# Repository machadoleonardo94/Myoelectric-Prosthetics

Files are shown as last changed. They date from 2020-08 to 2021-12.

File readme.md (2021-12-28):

# Intro

### This is the prototype for actuating a stepper motor using EMG signals, with the final purpose of studying prosthetic devices. 

### Current model was developed for string based actuation like the e-NABLE hand found at https://enablingthefuture.org/ and still is a work in progress.

### The project started in 2018, and after my graduation it took a big hiatus. Updates are due, and I'm getting back to work with this concept in early 2022.

### Feel free to ask questions and colab in this development. 

### Proof of concept can be seen at https://www.youtube.com/watch?v=dRGHVrhc-jM

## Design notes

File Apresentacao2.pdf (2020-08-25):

# Próteses impressas

Leonardo Machado de Aguiar
Formação | Departamento de Engenharia Elétrica e Eletrônica | CTC

# Problema

### - Custo da prótese estética de membro superior: de

R$3000 a R$10000;

### - Desafio de adaptar o equipamento prostético às

necessidades do paciente;

### - Em Santa Catarina, segundo o IBGE 270 mil pessoas possuem deficiência motora

# Proposta

- Desenvolvimento de uma
prótese impressa, facilmente replicável e de código aberto
- Apoio de voluntários na área de impressão 3D doméstica e de profissionais de
fisioterapia.

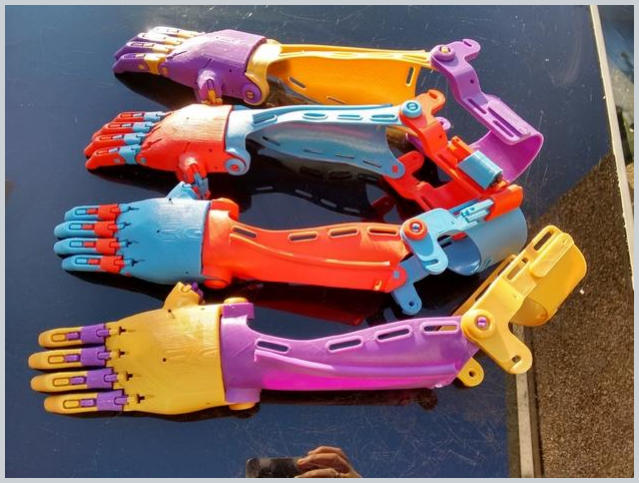
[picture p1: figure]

Prótese impressa sob licença Creative Commons – Não comercial.

# Origem

A prótese segue a base do
modelo Alfie, desenvolvido por Drew Murray e Stephen Davies.

A partir do modelo de mão e sistema de movimentação por tensores e elásticos, foi
desenvolvido um suporte
eletromecânico acionado por sinal mioelétrico.

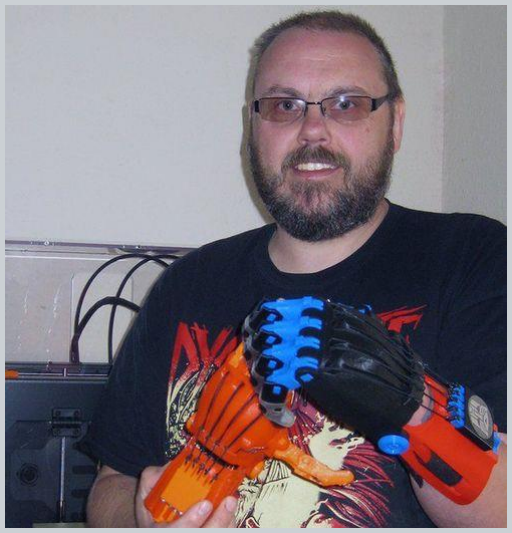
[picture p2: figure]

Stephen Davies, co-autor e primeiro usuário.

# Estado da arte

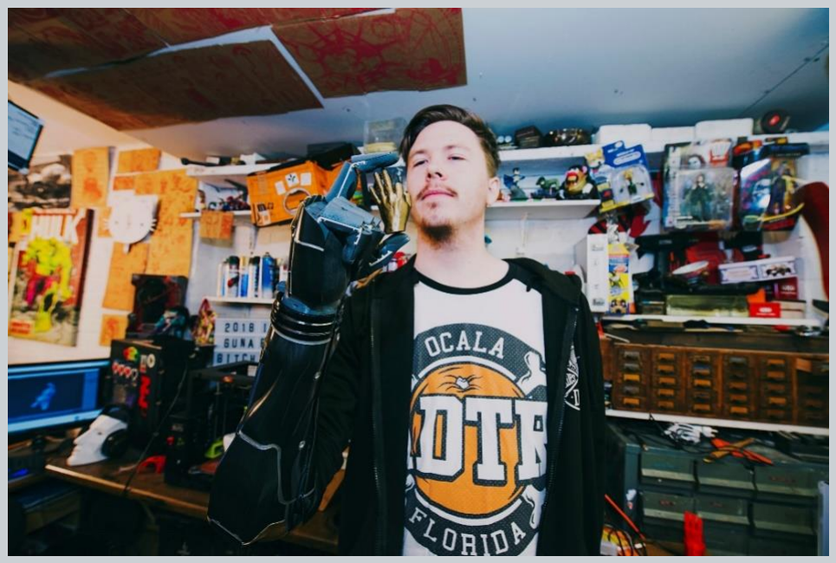
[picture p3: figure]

Prótese impressa da Open Bionics.

A empresa britânica Open
Bionics, fundada em 2014 por Joel Gibbard e Samantha
Payne, realiza pesquisa e
desenvolvimento na área de dispositivos prostéticos.

# Estado da Arte

## Além das próteses de

alto desempenho,

## qualidade e custo, possui em seu catálogo um módulo de pesquisa que inclui material didático e um modelo de mão

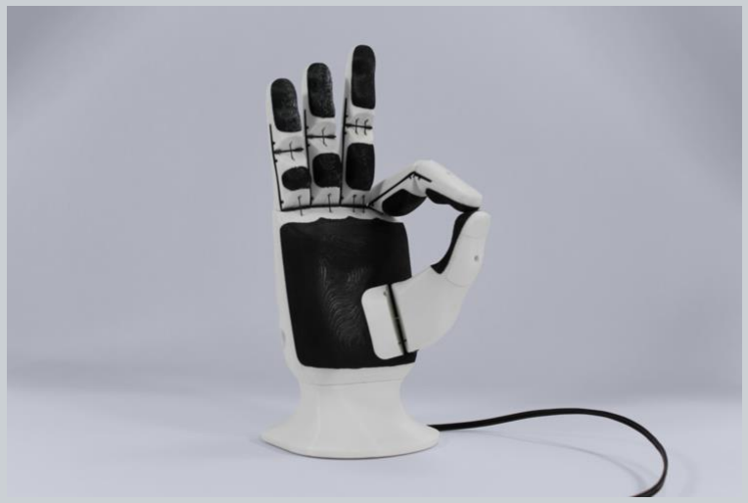
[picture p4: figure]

articulado por £1199,00. | Modelo Brunel Hand 2.0, Open Bionics 2018.

# Proposta

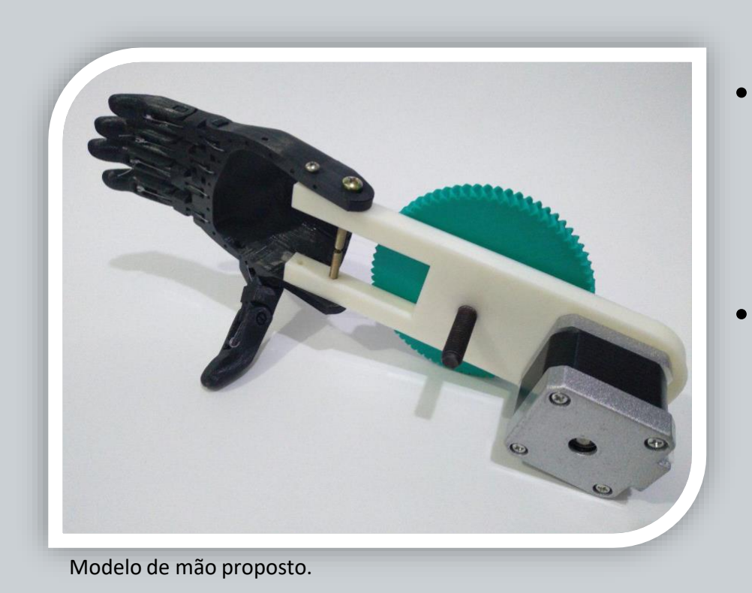
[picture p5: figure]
Modelo de mão proposto.

- Um dispositivo prostético educacional, replicável e de código aberto.
- Responder a estímulos
musculares e realizar
movimento de preensão
tetradigital.

# Fundamentação teórica

Niveis de amputação de membro superior:

- Desarticulação parcial de mão;
- Desarticulação de punho;
- Transradial;
- Desarticulação de cotovelo;
- Transumeral;
- Desarticulação de ombro;

# Fundamentação teórica

- A fibra muscular é uma célula excitável. O potencial de ação gerado pela contração
muscular altera a distribuição de cargas no fluído
extracelular.
- Esta variação de carga é conduzida por fluidos
corporais, e pode ser
detectada na superfície da pele por meio de eletrodos.

# Fundamentação teórica

- O sinal biomédico de interesse é o mioelétrico captado na superfície da pele. Sua banda de interesse vai dos 20 Hz aos 500Hz, e é contaminado por ruído, interferência de músculos próximos
- batata

# Diagrama de blocos

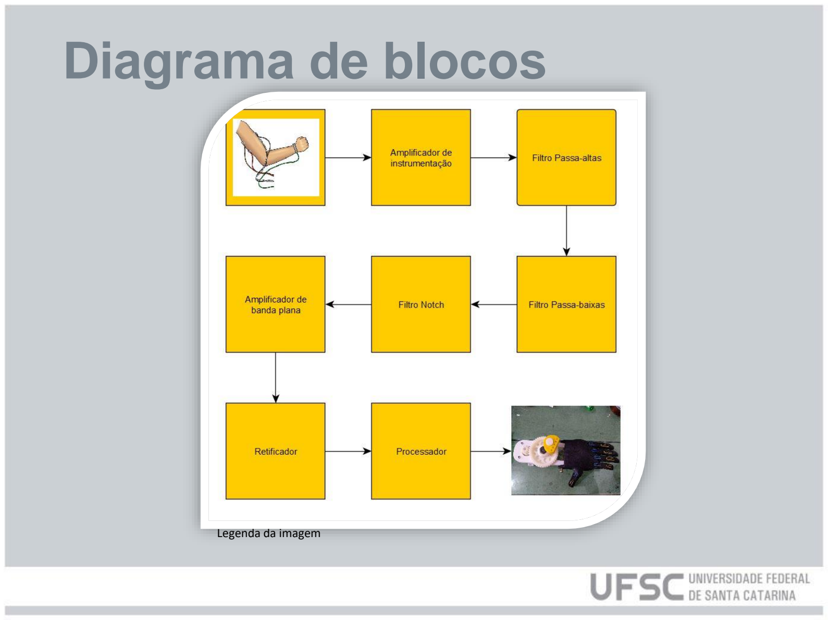
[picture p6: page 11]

Legenda da imagem

# Necessidade de filtragem

## Para remover artefatos indesejados, foram adicionados filtros seletores de sinal:

- Amplificador diferencial;
- Filtro passa-altas 20Hz;
- Filtro passa-baixas 500Hz;
- Filtro Notch 60Hz.

# Amplificador diferencial

- Ganho diferencial;

## - Rejeição do modo

comum;

## - Estágio de ganho

elevado;

## - Impedância de entrada na ordem de

mega Ohm.

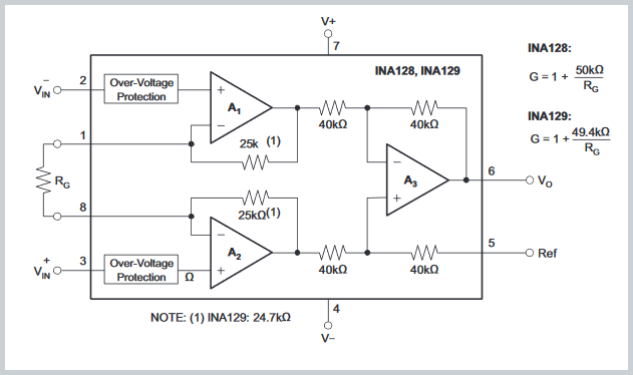
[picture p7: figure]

Esquematico simplificado do amplificador diferencial INA128

# Etapa de filtragem

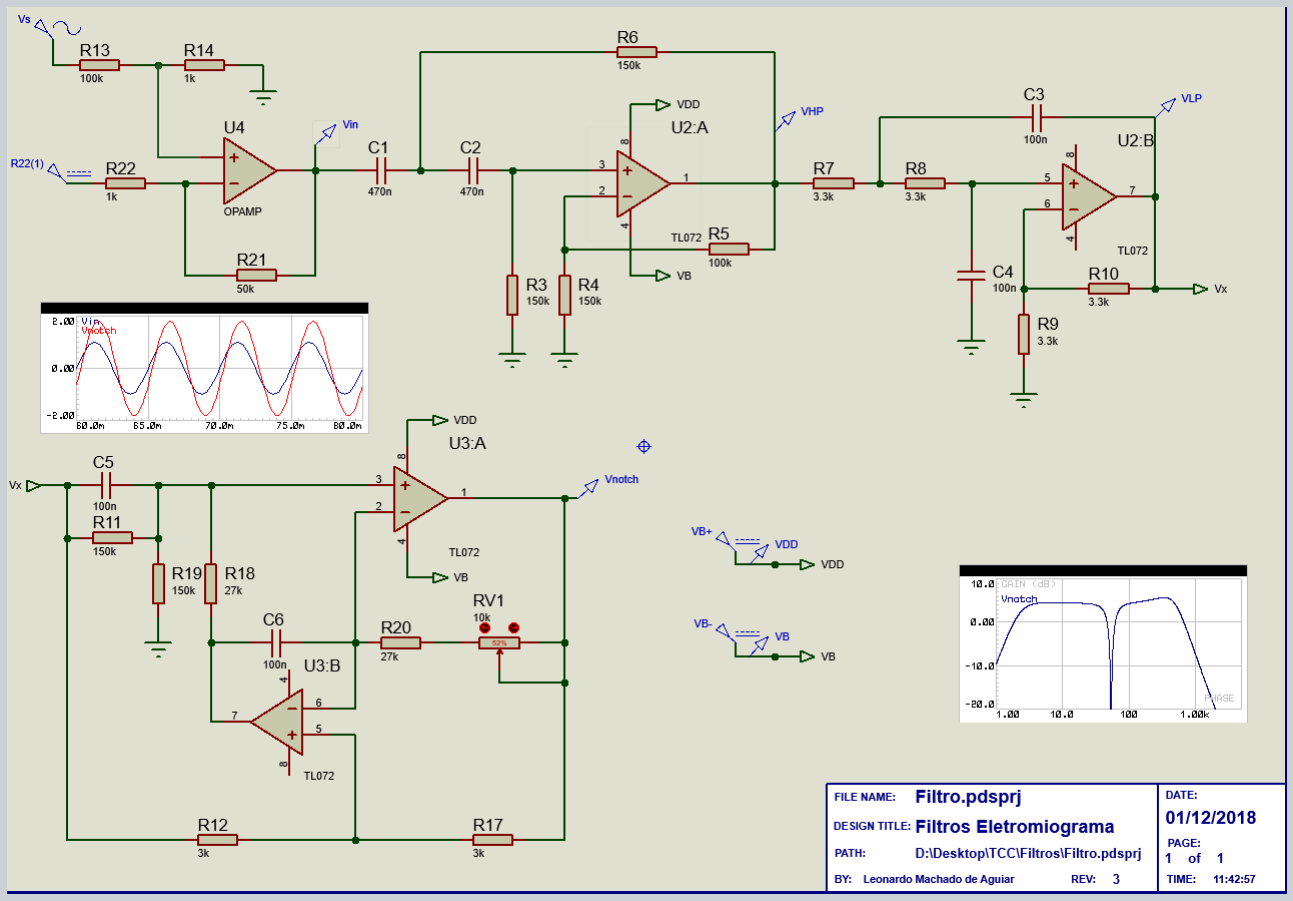
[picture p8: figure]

Etapa do filtro seletor de sinal. Cascata de Sallen-Key e Notch

# Retificação e proteção

## - Para realizar o processamento, se optou por um Arduino Nano, com microcontrolador

ATMega168p.

## - Limitações: taxa de amostragem e amplitude da leitura analógica

# Retificador de precisão

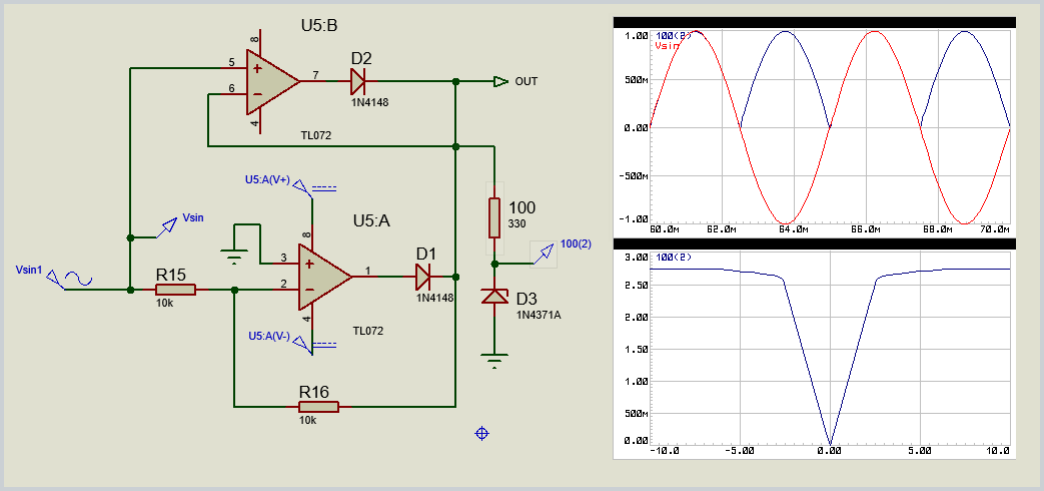
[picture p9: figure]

Retificador a amplificador operacional com proteção contra sobre-tensão. Gráfico de resposta no tempo a sinal sinusoidal 200Hz 1Vp e função de transferência da tensão de saída para uma variação de tensão de entrada de -10V a 10V

# Esquemático final

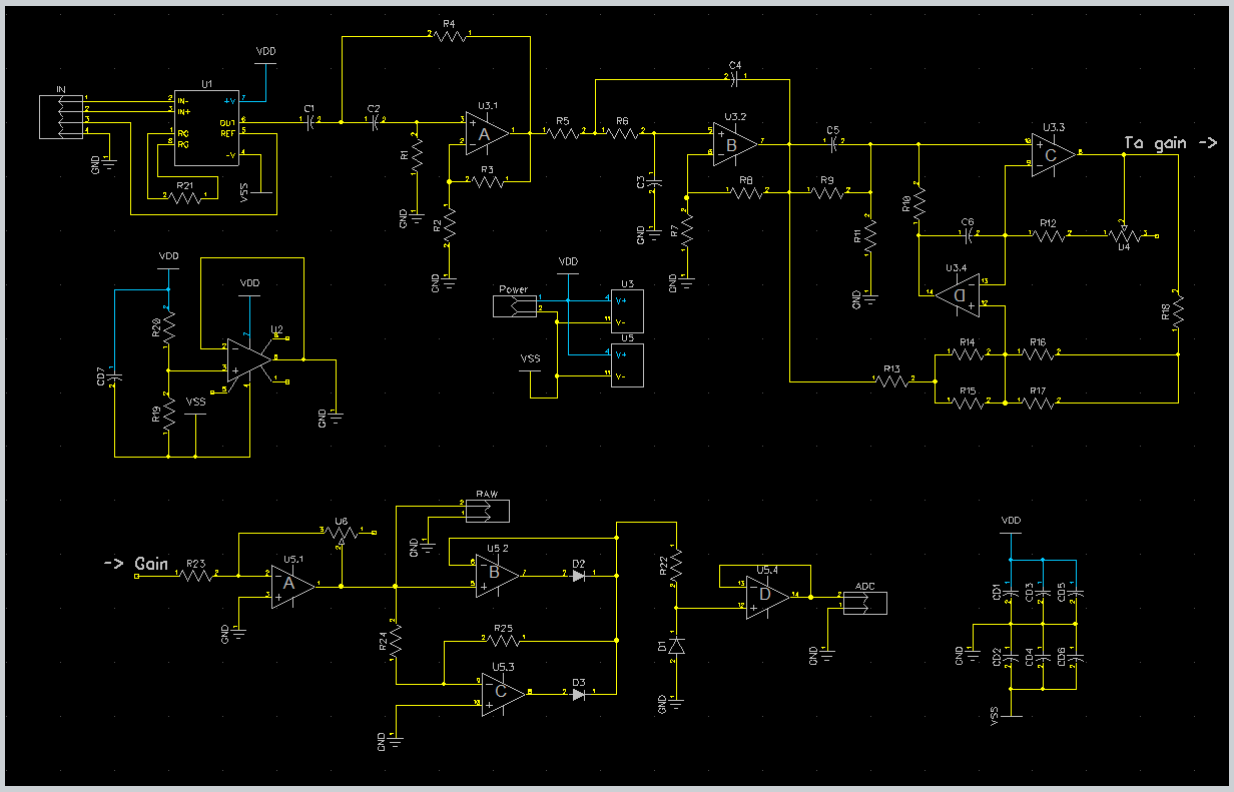
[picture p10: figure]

Esquemático completo portado para o DIP Trace

# Projeto da PCI

### - Resistores com tolerância 1% 0805 - Capacitores com tolerância 5% 0805 - Amplificador operacional TL074 SOIC - Amplificador de instrumentação INA128P SOIC

### - Componentes e conectores comprados em taydaelectronics.com - PCI produzida por pcbway.com

# Montagem da PCI

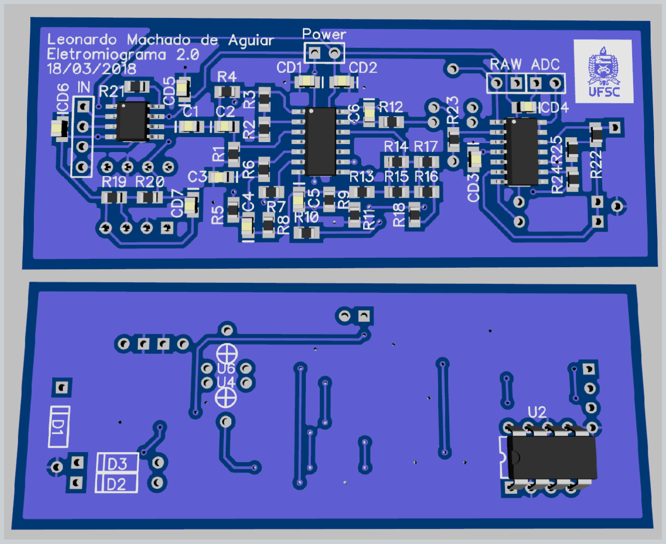
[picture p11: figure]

Renderização 3D do projeto de PCI

# Aquisição de dados

- Arduino realiza leitura analógica a cada 500us;

### - Amostra é armazenada em um vetor, substituindo a

amostra mais antiga;

### - Um algoritmo de média móvel realiza a detecção de

envoltória e uma filtragem adicional;

### - Motor é acionado se movimentando proporcionalmente

à potência do sinal processado;

# Modelagem da prótese

O projeto original consiste em arquivos STL escaláveis conforme a necessidade do paciente, acionados por tensores. Para unir o modelo ao motor e realizar movimento de preensão tetradigital, foi desenvolvido um suporte com engrenagens no software Fusion 360.
O suporte une duas engrenagens com 72 e 9 dentes por meio de um parafuso M8 30mm apoiado por um rolamento 608

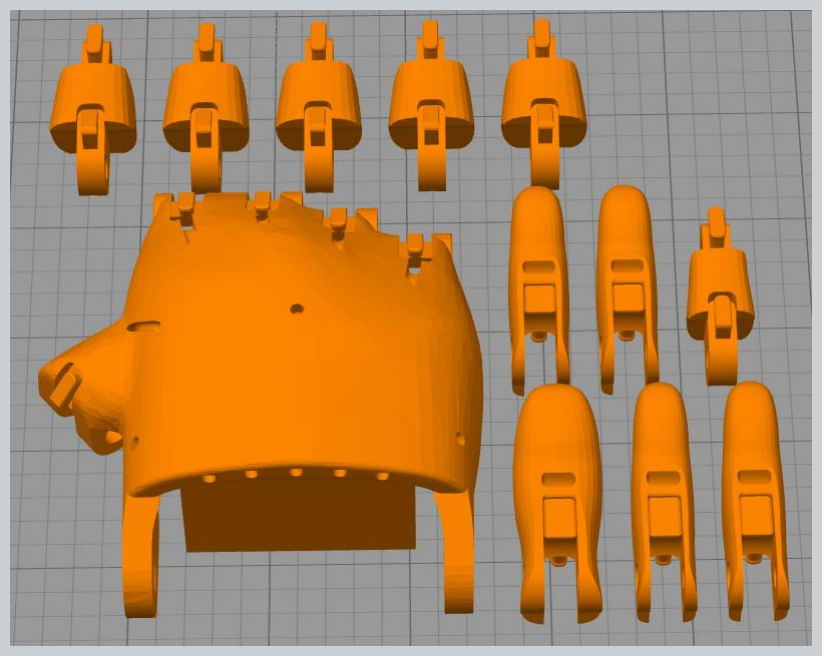
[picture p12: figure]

Modelo 3D da mão

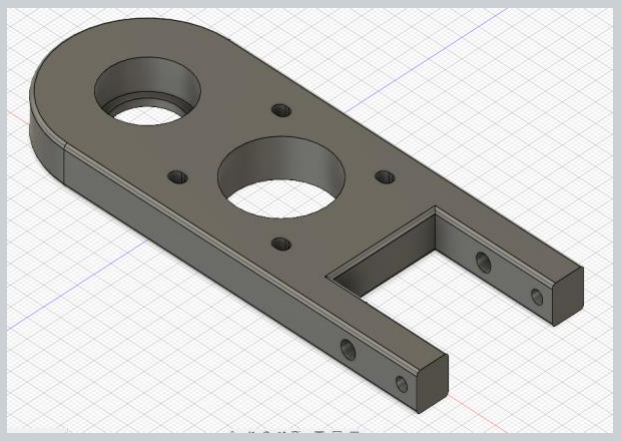
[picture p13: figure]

Peça de união e suporte

# Impressão da prótese

Por meio de fabricação por filamento fundido (FFF), com uma impressora de uso
doméstico, foi confeccionada a primeira prótese. O modelo foi confeccionado em ABS,
consumiu 100g de filamento e um tempo total de impressão de 12 horas.

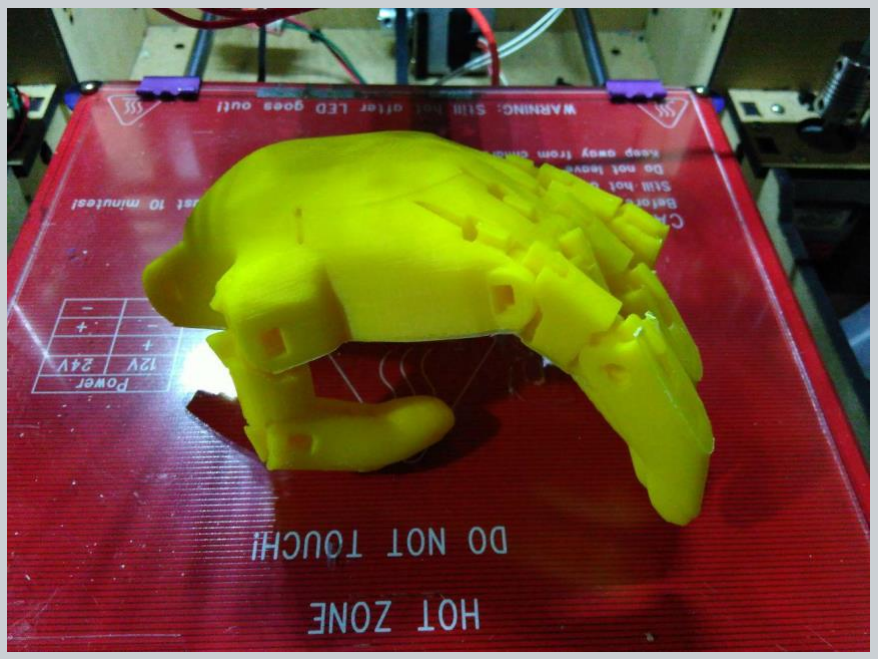
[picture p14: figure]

Prótese impressa e montada

## Montagem Final

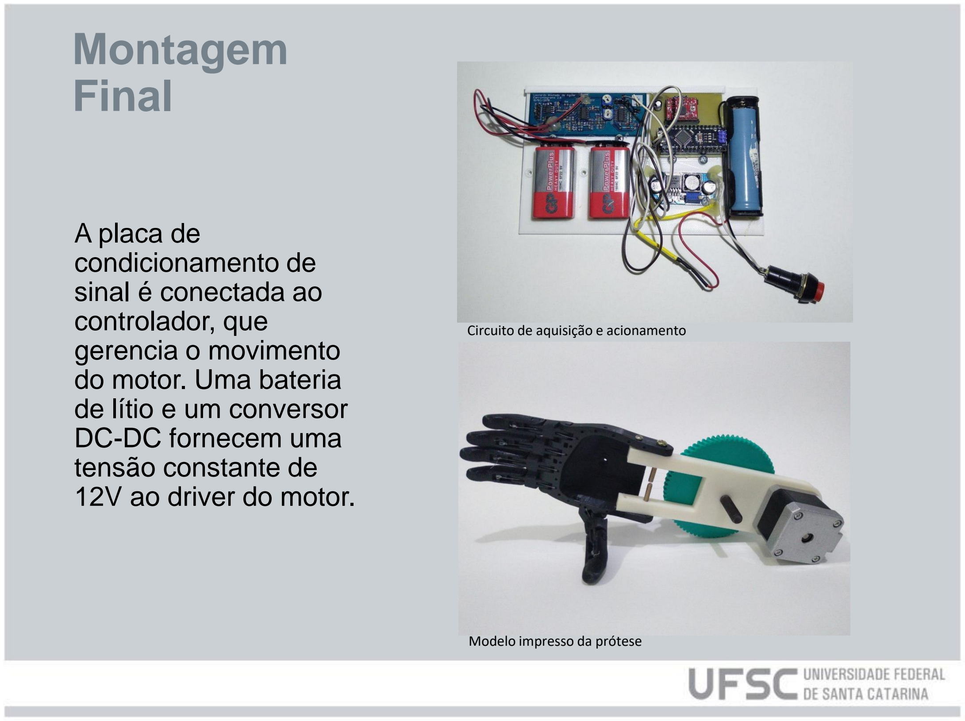
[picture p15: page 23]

A placa de
condicionamento de
sinal é conectada ao
controlador, que
gerencia o movimento
do motor. Uma bateria
de lítio e um conversor
DC-DC fornecem uma
tensão constante de
12V ao driver do motor.

Circuito de aquisição e acionamento

Modelo impresso da prótese

# Estrutura final

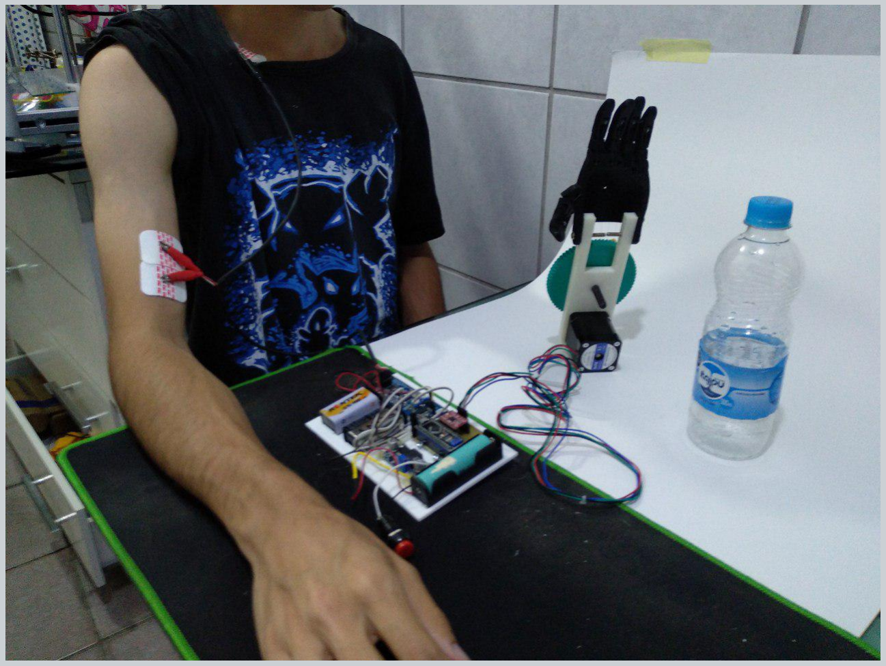
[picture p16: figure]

Circuito de aquisição conectado ao paciente

# Testes

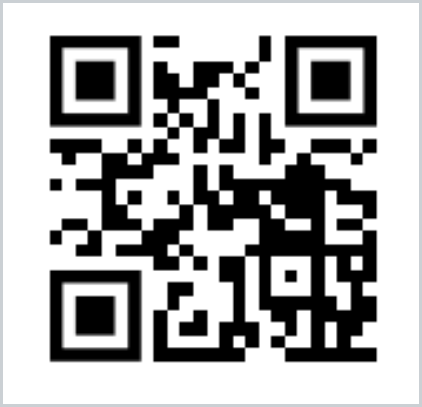
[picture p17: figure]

# Possíveis melhorias

### - Adição de canais de eletromiografia para maior grau

de liberdade;
- Alteração do motor de passo para servo motor;

### - Refinamento do código de detecção de movimento

para conferir maior grau de customização;

### - Realizar testes em pacientes com agenesia e

amputados recentes para comparação de resultados;

Contato

E-mail: machado.Leonardo94@gmail.com

Telefone: (48) 99625-8235

Site: https://sites.google.com/view/aleoexpress/

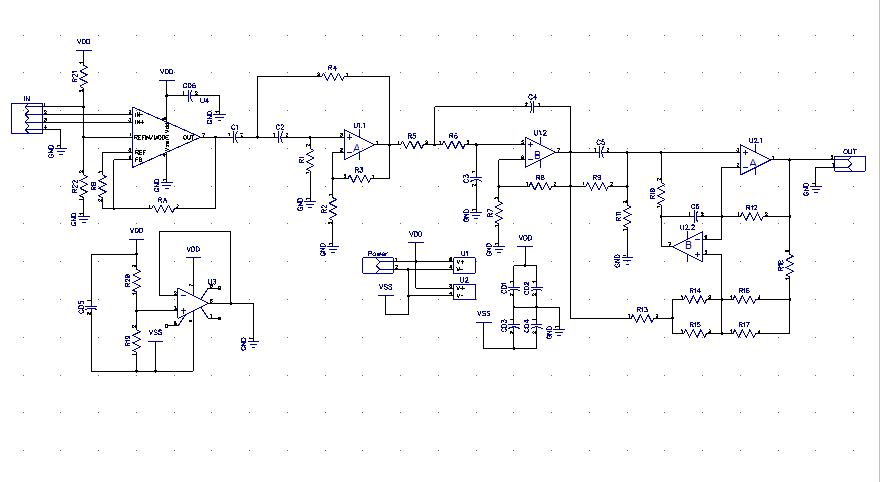
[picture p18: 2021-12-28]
Circuits/Eletromiograma/esq.png

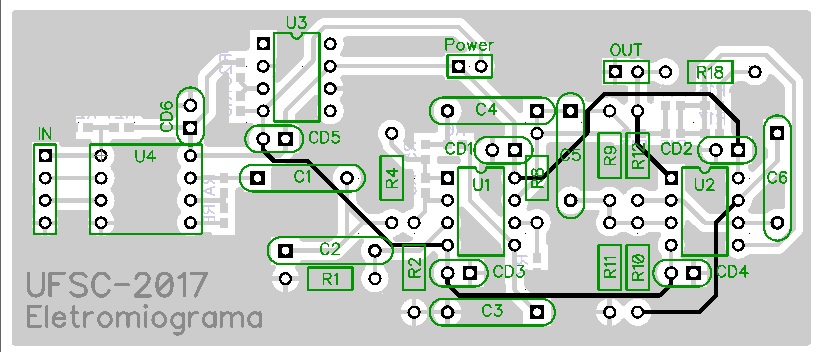
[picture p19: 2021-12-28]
Circuits/Eletromiograma/leiaute.jpg

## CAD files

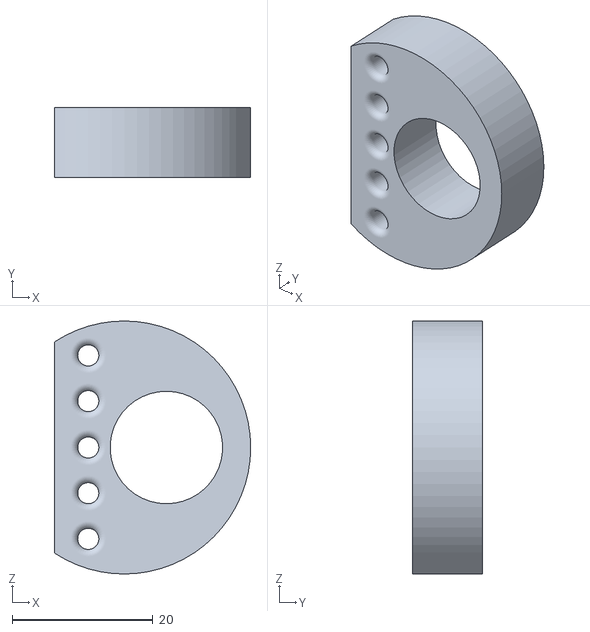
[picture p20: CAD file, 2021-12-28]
3d_models/swivel2.STL
27.9 x 10.0 x 36.0

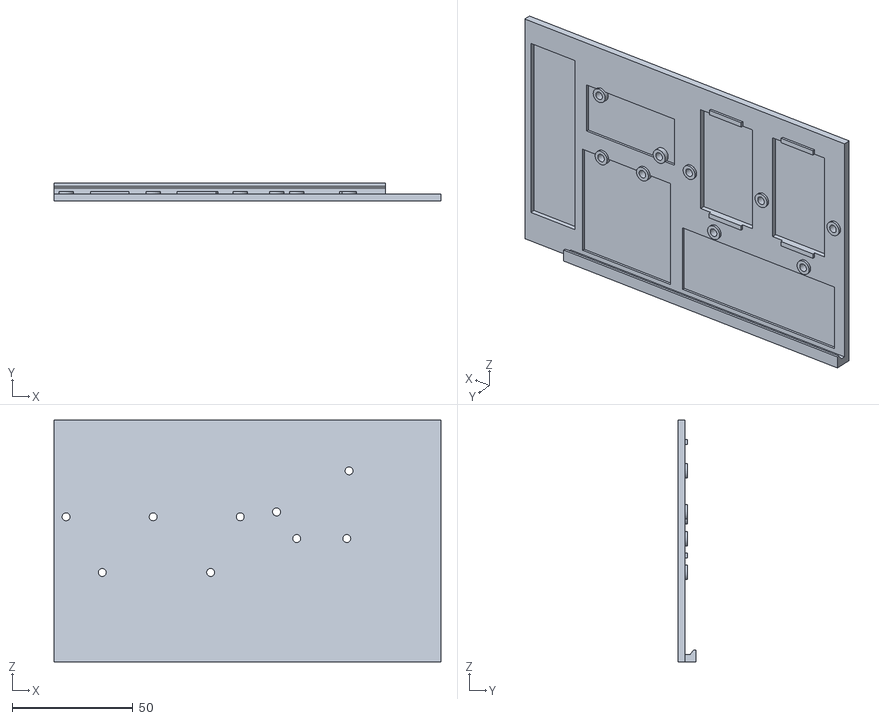
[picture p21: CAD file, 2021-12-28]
3d_models/suporte_plaquinhas v5.stl
160.0 x 7.50 x 100.0

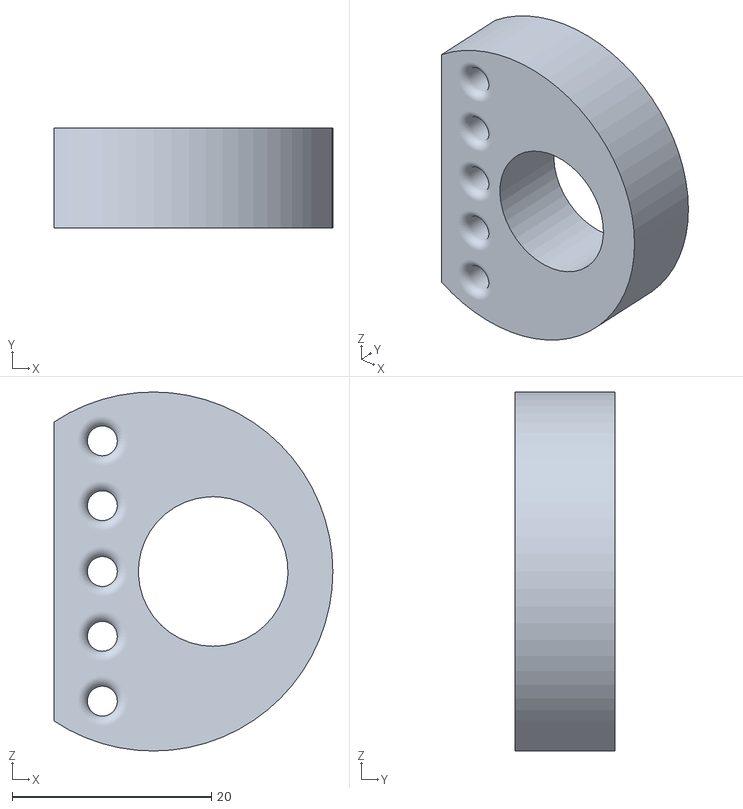
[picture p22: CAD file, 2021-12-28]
3d_models/swivel.STL
27.9 x 10.0 x 36.0

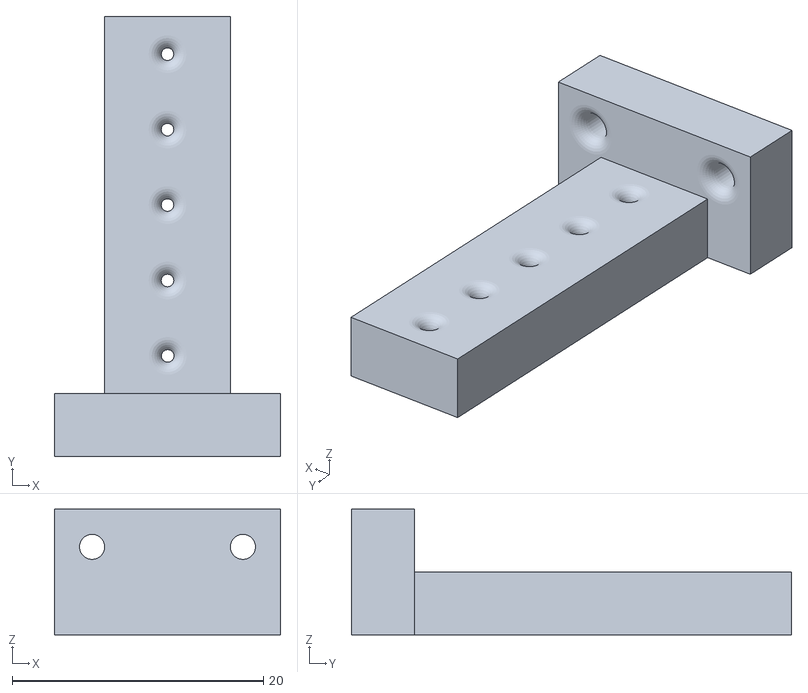
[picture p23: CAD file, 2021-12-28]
3d_models/guia polia.stl
18.0 x 35.0 x 10.0

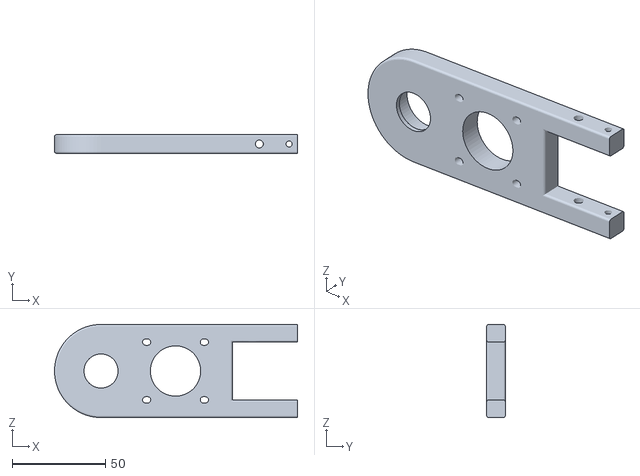
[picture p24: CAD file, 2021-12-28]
3d_models/montante_nema_gear40.stl
130.5 x 10.0 x 50.0

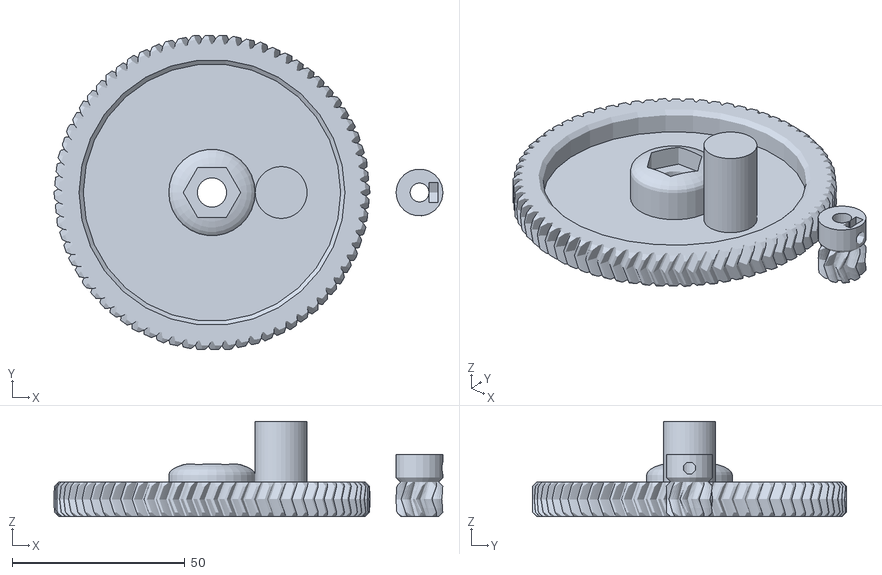
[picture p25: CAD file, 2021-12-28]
3d_models/gear-9-72-pivot15mm.stl
112.5 x 90.9 x 27.5

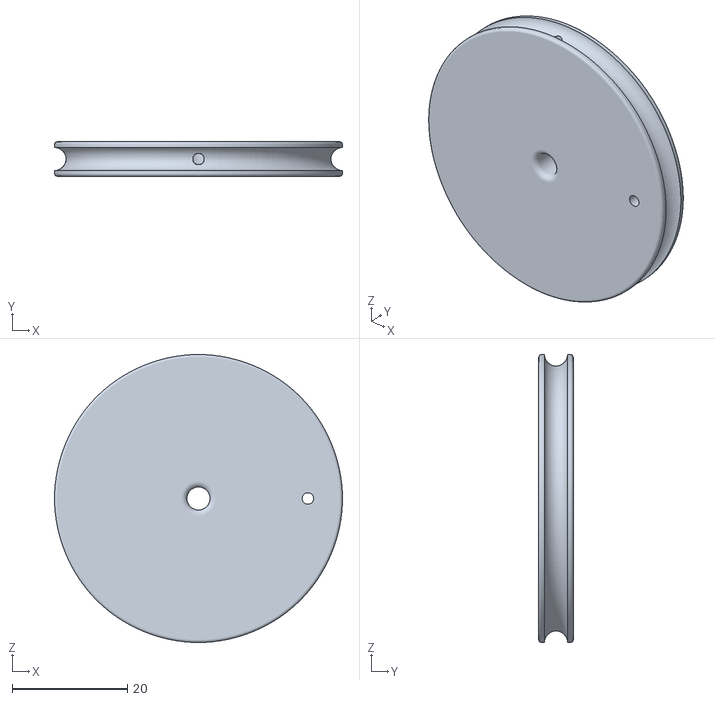
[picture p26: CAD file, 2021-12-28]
3d_models/polia 50mm.stl
50.0 x 6.00 x 50.0

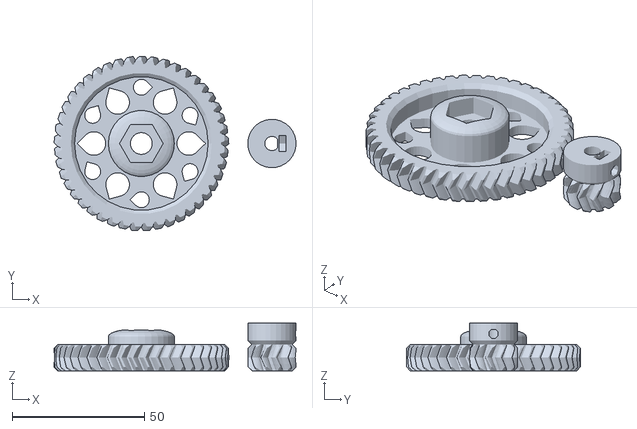
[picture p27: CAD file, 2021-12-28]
3d_models/engrenagens.stl
91.7 x 65.9 x 18.0

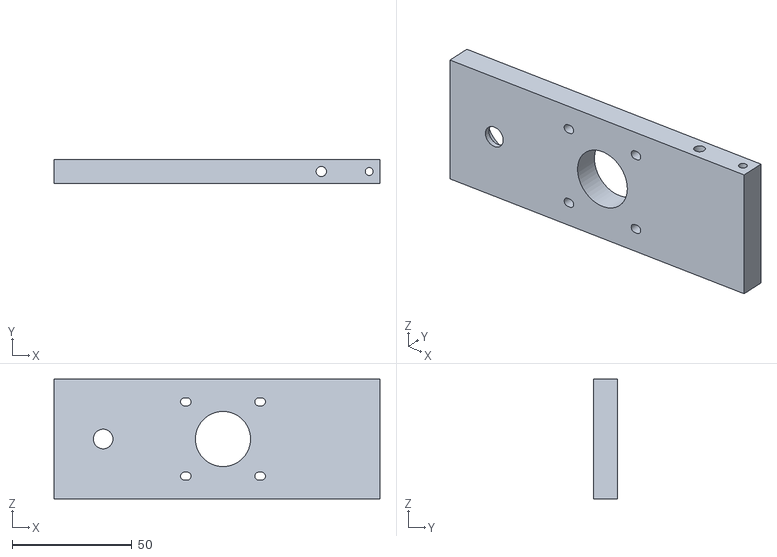
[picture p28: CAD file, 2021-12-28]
3d_models/montante_nema.stl
136.0 x 10.0 x 50.0

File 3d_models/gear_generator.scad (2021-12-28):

// OpenSCAD Herringbone Wade's Gears Script
// (c) 2015, Frans-Willem Hardijzer
//
// Thanks to Christopher "ScribbleJ" Jansen for the inspiration and most of the calculations
// Thanks to Greg Frost for the "Involute Gears" script.

include <MCAD/involute_gears.scad> 
include <MCAD/teardrop.scad> 

/*************************\
 * General Configuration *
\*************************/

/* Set to 1 to render gears as cylinders instead,
 * Will speed up rendering for experimenting with decorations.
 */
debug = 0;

/* Set to 0 to render the gears interlocked,
 * or 1 to render them seperately for easy printing.
 */
printing = 1;
 
/* Distance between the midpoints of the two gears
 * Copy this from your extruders' information.
 */
distance_between_axles = 50;

/* Height of the actual gear teeth
 */
gear_height = 10; //Height of the actual gears

/* Gear "twist": how slanted the gears are.
 * A value of 1 means each tooth will slant up one additional tooth.
 */
teeth_twist = 1;

/* Chamfer gradient, tan(45) degrees works nicely.
 * Use -1 to disable chamferred edges.
 */
chamfer_gradient = tan(45);

/****************************\
 * Small gear configuration *
\****************************/

/* Number of teeth on the gear */
gear1_teeth = 9;

/* Height of the base (for the setscrew) */
gear1_base_height = 8;

/* Shaft diameter
 * Be sure to add some tolerance for printer error
 */
gear1_shaft_diameter = 5 + 0.4;
/* Set-screw diameter, mind tolerance */
gear1_setscrew_diameter = 3 + 0.4;
/* Set-nut width, measured across the flat sides,
 * mind tolerance
 */
gear1_setnut_width = 5.5 + 0.4;
/* Set-nut height, mind tolerance */
gear1_setnut_height = 2.4 + 0.2;

/**************************\
 * Big gear configuration *
\**************************/
/* Number of teeth */
gear2_teeth = 72;
/* Extra size of the outer rim */
gear2_outer_thickness = 6;

/* Shaft diameter
 * Be sure to add some tolerance for printer error
 */
gear2_shaft_diameter = 8 + 0.4;

/* Height of the shaft embedded in the gear.
 * Measure
 *   X:
 *     Distance from the bottom of the nut on the hobbed bolt,
 *     to the middle of the hobbed part.
 *   Y:
 *     Distance from outside of gear-side of extruder,
 *     Including bearing, rings, and spacers,
 *     to the middle of the filament path.
 * This parameter should be equal to:
 *   X - Y
 */
/*
 * Some example measurements:
 * Silver hobbed bolt part of my Replikeo Prusa i3 kit:
 *   X: 24.5mm
 * Black hobbed bolt bought at aliexpress
 *   X: 28mm
 * Jonas Kuehling's Greg's Wade Reloaded,
 * with two M8 spacing rings:
 *   Y: 18.5mm
 */
gear2_shaft_height = 9.5;

/* Diameter of shaft holder */
gear2_middle_diameter = 25;

/* Height of shaft holder rounding */
gear2_middle_rounding = 4;

/* Shaft nut width, measured across the flat sides,
 * mind tolerance
 */
gear2_nut_diameter = 14 + 0.4;

/* Depth that the nut should be sunk inside the holder */
gear2_nut_sunk = 6.5;

/* Which decorations to use */
gear2_decoration_solid = true;
gear2_decoration_spokes = 0; //Set to number of desired spokes
gear2_decoration_arcs = 0; //Set to number of desired arcs
gear2_decoration_spiral1 = 0; //Set to number of desired spirals (style 1)
gear2_decoration_spiral2 = 0; //Set to number of desired spirals (style 2)
gear2_decoration_arrows = 0; //Set to number of desired arrows
gear2_decoration_drops = 0; //Set to number of desired drops
gear2_decoration_holes = 0; //Set to number of desired holes
gear2_decoration_flower = 0; //Set to number of petals (7 is nice)
gear2_decoration_segments = 0; //Set to number of desired segments
gear2_decoration_extra_margin = 0; //Number of millimeters

/* Height of decoration */
gear2_decoration_height = gear_height/3;

/********************\
 * Pre-calculations *
\********************/
circular_pitch = 360*distance_between_axles/(gear1_teeth+gear2_teeth);

/********************\
 * Helper functions *
\********************/
//Distance to overlap things that should be joined.
epsilon = 0.01;

function gear_radius(number_of_teeth, circular_pitch) = number_of_teeth * circular_pitch / 360;

function gear_outer_radius(number_of_teeth, circular_pitch) = gear_radius(number_of_teeth=number_of_teeth, circular_pitch=circular_pitch) + (circular_pitch/180);

function gear_inner_radius(number_of_teeth, circular_pitch) = gear_radius(number_of_teeth=number_of_teeth, circular_pitch=circular_pitch) - (circular_pitch/180);

module mirrordupe(p) {
    children();
    mirror(p) children();
}

module chamfered_herring_gear(height, chamfer_gradient, teeth_twist, number_of_teeth, circular_pitch) {
    radius = gear_radius(number_of_teeth=number_of_teeth, circular_pitch=circular_pitch);
    outer_radius = gear_outer_radius(number_of_teeth=number_of_teeth, circular_pitch=circular_pitch);
    twist = 360 * teeth_twist / number_of_teeth / 2;

    edge = (outer_radius - radius) / chamfer_gradient;
    intersection() {
        union() {
            if (debug == 1) {
                cylinder(h=height, r=outer_radius);
            } else {
                translate([0,0,height/2])
                    mirrordupe([0,0,1])
                        translate([0,0,-epsilon])
                            gear(
                                twist=twist,
                                number_of_teeth=number_of_teeth,
                                circular_pitch=circular_pitch,
                                gear_thickness = (height/2) + epsilon,
                                rim_thickness = (height/2) + epsilon,
                                hub_thickness = (height/2) + epsilon,
                                bore_diameter=0);
            }
        }
        //Cut edges
        union() {
            cylinder(h=edge + epsilon, r1=radius, r2=outer_radius + epsilon*chamfer_gradient);
            translate([0,0,edge])
                cylinder(h=height-2*edge, r=outer_radius);
            translate([0,0,height-edge-epsilon])
                cylinder(h=edge + epsilon, r2=radius, r1=outer_radius + epsilon*chamfer_gradient);
        }
    }
}

module hole(h,r,$fn=8,rot=0) {
    rotate([0,0,rot * (180/$fn)])
        cylinder(h=h, r=r / cos(180 / $fn), $fn=$fn);
}

module gear1() {
    //Variables
    radius = gear_radius(gear1_teeth, circular_pitch);
    inner_radius = gear_inner_radius(gear1_teeth, circular_pitch);
    outer_radius = gear_outer_radius(gear1_teeth, circular_pitch);
    base_chamfer = (outer_radius - radius) / chamfer_gradient;
    shaft_radius = gear1_shaft_diameter/2;
    setnut_distance = shaft_radius;//(shaft_radius + radius - gear1_setnut_height)/2;
    
    difference() {
        union() {
            //Actual gear
            chamfered_herring_gear(height = gear_height, chamfer_gradient = chamfer_gradient, teeth_twist=teeth_twist,     number_of_teeth=gear1_teeth, circular_pitch=circular_pitch);
            //Base
            translate([0,0,-gear1_base_height]) {
                cylinder(h=gear1_base_height + epsilon, r=inner_radius);
                cylinder(h=gear1_base_height - base_chamfer, r=outer_radius);
                translate([0,0,gear1_base_height - base_chamfer - epsilon]) {
                    intersection() {
                        cylinder(h=base_chamfer + epsilon, r2=radius, r1=outer_radius + chamfer_gradient * epsilon);
                        cylinder(h=base_chamfer + epsilon, r=outer_radius);
                    }
                }
            }
        }
        //Shaft
        translate([0,0,-gear1_base_height - epsilon])
            hole(h=gear_height + gear1_base_height + 2*epsilon, r=shaft_radius, $fn=24);
        //Setscrew shaft
        translate([0,0,-gear1_base_height/2]) {
            rotate([0,-90,0]) {
                hole(h=outer_radius + epsilon, r=gear1_setscrew_diameter/2, $fn=8, rot=1);
                translate([0,0,setnut_distance])
                    hole(h=gear1_setnut_height, r=gear1_setnut_width/2, $fn=6);
            }
        }
        //Setscrew insertion cube
        translate([-setnut_distance-gear1_setnut_height,-gear1_setnut_width/2,-gear1_base_height-epsilon])
            cube([gear1_setnut_height, gear1_setnut_width, gear1_base_height/2 + epsilon]);
        
    }
    
}
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

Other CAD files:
3d_models/suporte_plaquinhas v4.stl

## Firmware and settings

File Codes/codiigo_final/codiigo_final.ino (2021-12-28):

#include <Arduino.h>
#include "BasicStepperDriver.h"

#define MOTOR_STEPS 200
#define RPM 60
#define numSamples 100
#define MICROSTEPS 32
#define SENSIBILIDADE 5

BasicStepperDriver stepper(MOTOR_STEPS, 4, 5);  //DIR pino 4, STEP pino 5


void setup() {
  stepper.begin(RPM, MICROSTEPS);
  pinMode(A0, INPUT);
  pinMode(3, OUTPUT);
  Serial.begin(57200);
}

  int indice=0; //indice do vetor de amostras
  int amostra[numSamples]={0};  //vetor de amostras
  long media=0; //meddia da amostragem
  int posicao=0;//posicao do arco
  int delta=0;  //variacao na posição
  int k=0;      //contador genérico
  int offset=0; //correção de leitura, implementar depois
  int debug=1;


void loop() {

  //amostragem
  amostra[indice]=analogRead(A0);
  for(k=0;k<numSamples;k++)
    media+=amostra[k];
  media=media/numSamples;
  indice++;
  if(indice>numSamples){
    indice=0;
  }

  //mapeia posição para ser a intensidade do movimento
  media = map(media,20,800,0,100);   //anota nova
  delta = media-posicao;

  if (debug){  
    Serial.print(0);
    Serial.print(" ");
    Serial.print(100);
    Serial.print(" ");
    Serial.print(media);
    Serial.print(" ");
    Serial.println(posicao);
  }
  

  if ((delta<-SENSIBILIDADE) && (posicao>2) && (media<30)){      //se deslocamento negativo e dentro dos limites
    stepper.move(-60);
    posicao--;
  }
  if ((delta>SENSIBILIDADE) && (posicao<100)){      //se deslocamento positivo e dentro dos limites
    stepper.move(60);
    posicao++;
  }
  
  media=0;
}

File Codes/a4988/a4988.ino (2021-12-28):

const int stepPin = 4; 
const int dirPin = 3; 
const int timer=4000;
 
void setup() {
  // Sets the two pins as Outputs
  pinMode(stepPin,OUTPUT); 
  pinMode(dirPin,OUTPUT);
  digitalWrite(dirPin,HIGH);
}
void loop() {
    digitalWrite(stepPin,HIGH); 
    delayMicroseconds(timer);
    digitalWrite(stepPin,LOW); 
    delayMicroseconds(timer);
}

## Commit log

2020-08-25 First Push
    Schematic file;
    Layout files;
    Submission documentation;
    Presentation slides.
2021-12-28 Fabrication files
    Outdated, requires a major rework and a tutorial on how to replicate
    [BoardOutline.gbr, Bottom.gbr, BottomAssy.gbr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]
